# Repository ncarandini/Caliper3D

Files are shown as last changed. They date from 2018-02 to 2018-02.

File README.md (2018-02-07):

# Caliper3D
This project use a PC with Windows 10, an Arduino Nano with a LCD display and a digital caliper to measure the geometry of the printing bed of a 3D printer.
<p align="center">
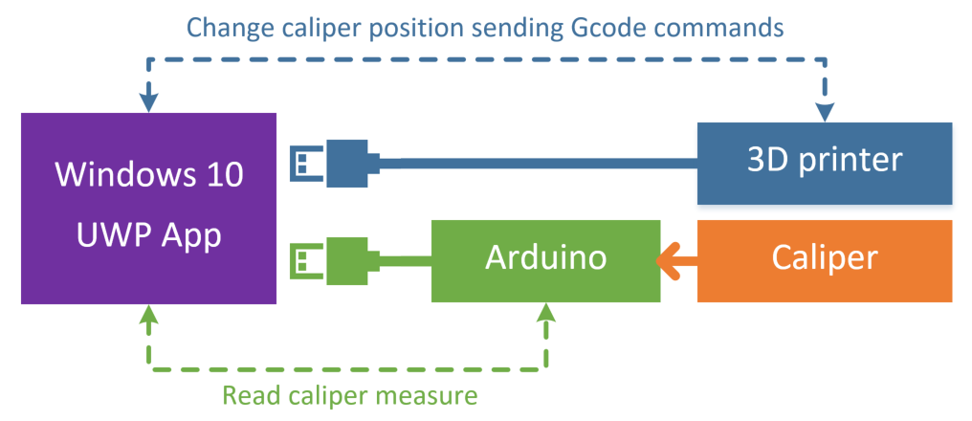
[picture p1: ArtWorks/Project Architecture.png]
Project architecture
  
</p>

## Bill of materials
Links refer to Amazon Italy, but you can find it almost everywere:

### Windows 10 PC
Your everyday Windows 10 PC.
Note that because two usb port are required to connect to the Arduino and the 3D Printer, if your PC has only one then you need a USB Hub to connect to both devices at the same time, and the USB Hub need to be powered to give power to the Arduino via USB.

### Arduino Nano
Elegoo Nano V3.0 Scheda Elettronica Microcontrollore CH340 ATmega328P con Cavo USB per Arduino
https://www.amazon.it/dp/B071S5K67Z

### Seeedstudio Grove – LCD
https://www.amazon.it/Seeedstudio-Grove-LCD-Retroilluminazione-Rgb/dp/B01AFKPJ6O

### Caliper
Neoteck DTI LCD Compratore Centesimale Digitale
https://www.amazon.it/gp/product/B01H035DRO

## Caliper modding to connect to the serial port
The caliper comes with a serial port (no TTL or RS232 serial port, more on this later) but to take advantage of it, we need to open the caliper and solder four wires to the board:
<p align="center">
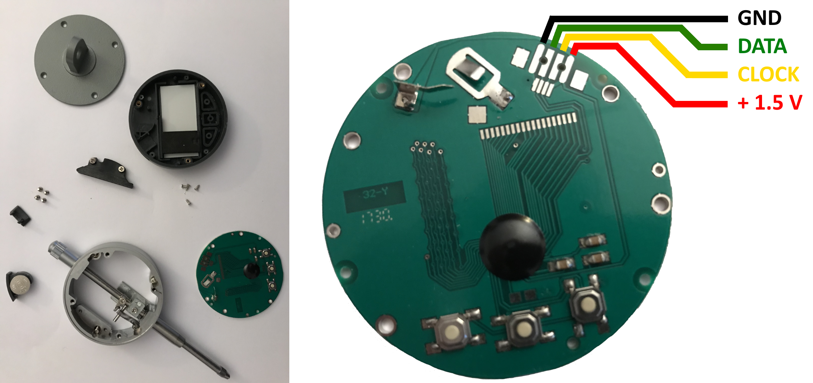
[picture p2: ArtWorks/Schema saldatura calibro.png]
Caliper cable soldering
  
</p>

## Breadboard circuit
Since the signal coming from the caliper use a 1.5 V logic that is too low to drive the digital input ports of arduino, then two amplifiers are used to convert the caliper 1.5V logic to the Arduino 5V logic. Moreover, we use a simple voltage divider to get +1.5VDC from the +5VDC power source to power the caliper. Beware not to connect the +5VDC to the caliper!
<p align="center">
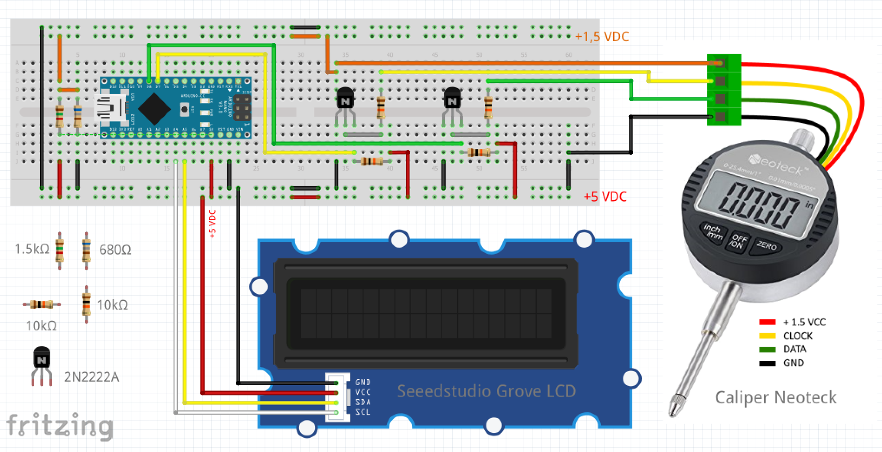
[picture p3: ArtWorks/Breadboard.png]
Breadboard circuit
  
</p>

## Mounting the caliper on the printing head of the 3D printer
It all depends on the 3D printer model you have. On my 3D printer has been an easy job, I only needed to change a screw with a longer one and fix the caliper on it with a washer and bolt.
<p align="center">
  Caliper mounted on the 3D printer
</p>

## Arduino Sketch
The Sketch loop Read the caliper measure and listen the (USB) serial port waiting for a command from the UWP App. Actually the only command is the R(ead) command, and when the Arduino receive it, it respond sending the last received caliper measure back to the UWP app via the (USB) serial port.

## Windows 10 UWP app
The UWP app is still a working progress, I'll add it to this repo A.S.A.P. and I'll update this readme with the pertinent infos.
<p align="center">
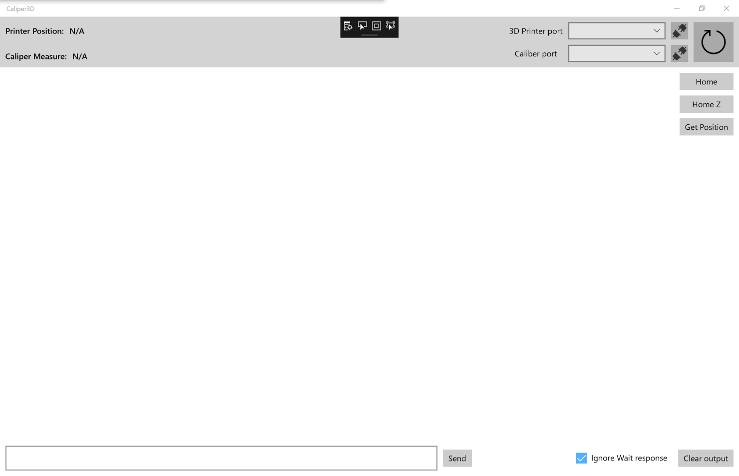
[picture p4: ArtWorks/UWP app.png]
UWP app screenshot
  
</p>

Stay tuned!

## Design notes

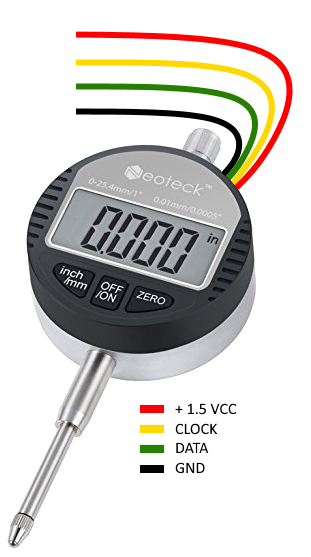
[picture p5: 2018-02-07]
ArtWorks/Schema segnali calibro.png

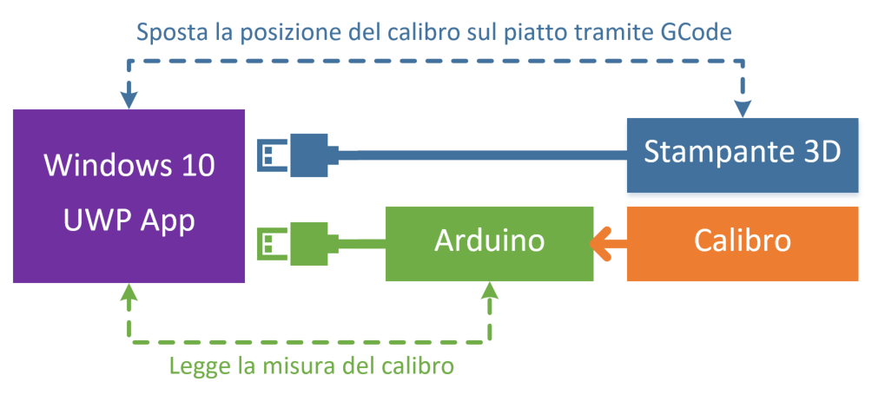
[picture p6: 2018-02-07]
ArtWorks/Architettura del progetto.png

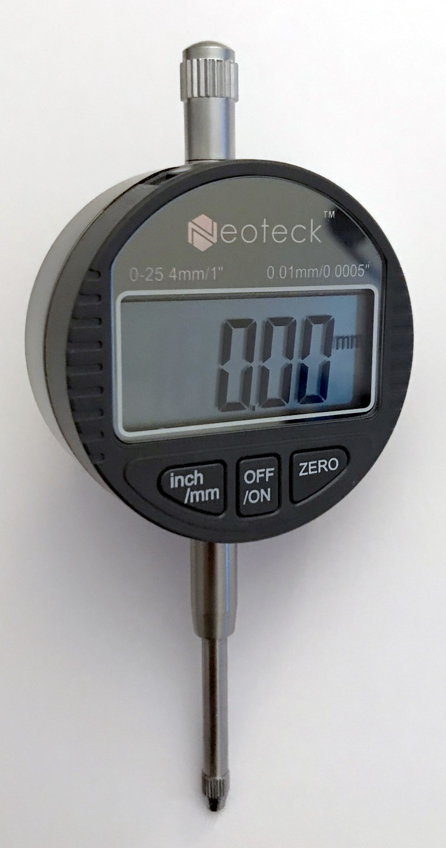
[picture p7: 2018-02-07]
ArtWorks/Calibro Neoteck.jpg

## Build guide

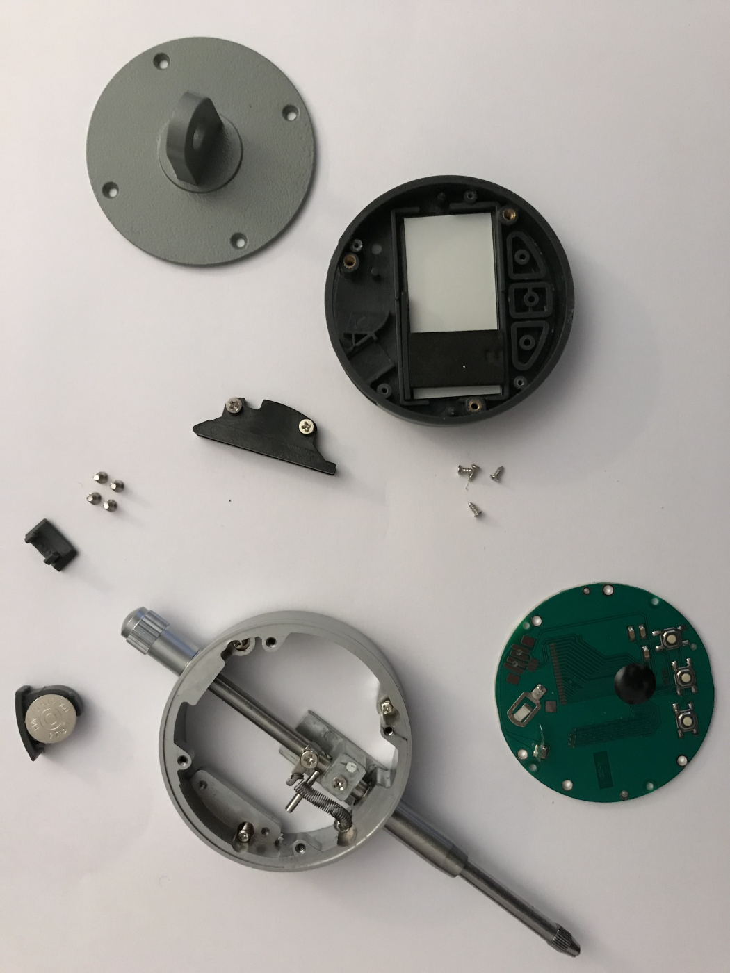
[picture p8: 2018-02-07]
ArtWorks/Smontaggio calibro.png

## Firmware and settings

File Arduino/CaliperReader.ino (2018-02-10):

// Copyright (c) 2018 TPCWare - Nicolò Carandini
//
// This file is licensed to you under the MIT License.
// See the LICENSE file in the project root for more information.
// 
// Author: Nicolò Carandini

#include <Wire.h>
#include "rgb_lcd.h"

rgb_lcd lcd;

const int colorR = 255;
const int colorG = 255;
const int colorB = 255;

const int clockPin = 7; // CLOCK signal connected to digital pin 7
const int dataPin = 8;  // DATA signal connected to digital pin 13

const unsigned long highTriggerTimeout = 120000; // 113,9 ms is the gap from the end of a measure message to the start of the next. More than this, the caliper is OFF.
const unsigned long lowTriggerTimeout = 800; // 631,208 us is the max gap from a lowTrigger and a next one in a message. More than this and we are out of sync.

const int maxNumberOfSync = 3;
const char versionTitle[16] = "Caliper reader";

bool bits[24];
int outOfSyncCounter;
bool readMeasureFailed;
bool caliperIsOn;
bool mmIsActive;
bool measureIsNegative;
int rawValue;
double measureValue;
char measureText[16];

char receivedCommand;

void setup() 
{
  Serial.begin(9600);
  
  pinMode(clockPin, INPUT); // sets the digital pin 7 as input
  pinMode(dataPin, INPUT);  // sets the digital pin 8 as input

  lcd.begin(16, 2); // set up the LCD's number of columns and rows
  lcd.setRGB(colorR, colorG, colorB); // set up the LCD's background color
  
  // Print the greeting message to the LCD, wait a second and clear it
  writeLineMessage(0, versionTitle);
  writeLineMessage(1, "by @TPCWare");
  delay(3000);
  writeLineMessage(1, "");
}

void loop() 
{
  // Try to get the measure
  readMeasure();
  
  // Show result on LCD
  if(!caliperIsOn)
  {
    writeLineMessage(1, "caliper is off");
    delay(1000);
  }
  else if(readMeasureFailed)
  {
    writeLineMessage(1, "Read error");
    delay(1000);
  }
  else
  {
    writeLineMessage(1, measureText);
    delay(100);
  }

  // receive command
  getCommand();
  
  if (receivedCommand == 'R') // Read command
  {
    // Send measure via serial port
    sendMeasure();
  
    // Send debug info via serial port
    // debugMeasure();
  }
}

void writeLineMessage(int line, String msg)
{
  lcd.setCursor(0, line);
  lcd.print("                ");
  lcd.setCursor(0, line);
  lcd.print(msg);
}

// Read the measure coming from the caliper.
// Set the result in global variables.
void readMeasure()
{
  int bitCounter;

  bool clockWasHigh;
  bool clockIsHigh;
  bool skippingData;
  
  readMeasureFailed = false;
  measureText[0] = 0;
  bitCounter = 0;
  outOfSyncCounter = 0;
  
  while (bitCounter < 24)
  {
    if (lowTrigger())
    {
      bits[bitCounter] = !digitalRead(dataPin); // Negation is required because the amplifier invert the DATA signal.
      bitCounter++;
    }
    else
    {
      outOfSyncCounter++;  // Increment the out of sync counter
      bitCounter = 0;      // Lets restart from bit one...
      
      // If we have not exceeded the max number of retries, we need to wait until the start of new message.
      // In case of timeout then we failed probably because the caliper is off.
      if (outOfSyncCounter > maxNumberOfSync or !highTrigger())
      {        
        readMeasureFailed = true;
        break;
      }
    }
  }

  if (readMeasureFailed)
  {
    caliperIsOn = false;
    mmIsActive = false;
    measureIsNegative = false;
    rawValue = 0;
    measureValue = 0.0;
    strcat(measureText, "N/A");
  }
  else
  {
    caliperIsOn = true;
    mmIsActive = !bits[23];
    measureIsNegative = bits[20];
    rawValue = bits[19];
    for (int i = 18; i >= 0; i--)
    {
      rawValue = rawValue << 1;
      rawValue += bits[i];
    }
    measureValue = ((measureIsNegative) ? -1 : 1) * rawValue / ((mmIsActive) ? 100.0 : 2000.0);
    dtostrf(measureValue, 4, ((mmIsActive) ? 2 : 4), measureText);
    strcat(measureText, ((mmIsActive) ? " mm" : " in"));
  }
}

// Wait for the Clock signal going from LOW value to HIGH value.
// Return true if this happens prior to the timeout, false elseware.
bool highTrigger()
{
  unsigned long start = micros();

  // Wait for the Low clock
  while(digitalRead(clockPin))
  {
      // Check timeout
      if(micros()-start > highTriggerTimeout)
      {
        return(false);
      }
  }

  // Wait for the High clock
  while(!digitalRead(clockPin))
  {
      // Check timeout
      if(micros()-start > highTriggerTimeout)
      {
        return(false);
      }
  }
  return true;
}

// Wait for the Clock signal going from HIGH value to LOW value.
// Return true if this happens prior to the timeout, false elseware.
bool lowTrigger()
{
  unsigned long start = micros();

  // Wait for the High clock
  while(!digitalRead(clockPin))
  {
      // Check timeout
      if(micros()-start > lowTriggerTimeout)
      {
        return(false);
      }
  }

  // Wait for the Low clock
  while(digitalRead(clockPin))
  {
      // Check timeout
      if(micros()-start > lowTriggerTimeout)
      {
        return(false);
      }
  }
  return true;
}

// Send the measure data via the serial port
void sendMeasure()
{
  Serial.print("[");
  Serial.print(measureText);
  Serial.println("]");
}

// Send the measurement debug data via the serial port
void debugMeasure()
{
  for (int i = 0; i < 24; i++)
  {
    Serial.print(bits[i] ? "1" : "0");
  }
  Serial.println("");
  for (int i = 23; i >= 0; i--)
  {
    Serial.print(bits[i] ? "1" : "0");
  }
  Serial.println("");  
  Serial.print("outOfSyncCounter: ");
  Serial.println(outOfSyncCounter);
  Serial.print("mmIsActive: ");
  Serial.println(mmIsActive);
  Serial.print("measureIsNegative: ");
  Serial.println(measureIsNegative ? "YES" : "NO");
  Serial.print("measureValue: ");
  Serial.println(measureValue);
  Serial.println("------------------");
}

// Get command
void getCommand()
{
  if (Serial.available() > 0)
  {
    receivedCommand = Serial.read();
  }
  else
  {
    receivedCommand = ' ';
  }
}

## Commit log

2018-02-07 Add Arduino Sketch
2018-02-07 Add Fritzing schema
    [Caliper Reader.fzz]
2018-02-07 Add copyright to Arduino Sketch
